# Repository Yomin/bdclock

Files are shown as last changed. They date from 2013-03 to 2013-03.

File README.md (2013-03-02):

# Bulbdial Clock Board

Board for the bulbdial clock developed at
[Evil Mad Scientist Laboratories](http://www.evilmadscientist.com/2009/a-bulbdial-clock/).
Due to current availability of only attiny45's the multiplexing is partly outsourced with
one 7bit binary counter and two 8bit addressable latches.

For synchronization the board is equipped with a socket for a pollin DCF77 module (810 054).

## License

MIT

## Parts

count|name|info
---|---|---|---
1x|attiny 25/45/85|
1x|HEF4024B|7 bit binary counter
1x|HCF4724B|8 bit addressable latch
2x|BC547B|
1x|red diffuse led|
1x|4pin socket|
1x|10pin isp socket|
1x|powerjack|
1x|2pin clamp|power
1x|3pin clamp|led gnd
1x|12pin clamp|led vcc
2x|1N4004|
1x|300nF|
1x|100nF|
1x|1uF pol|
1x|7805|
6x|10k|
1x|1k|
4x|250|
1x|pollin dcf77 module|
36x|white point leds|for the actual clock

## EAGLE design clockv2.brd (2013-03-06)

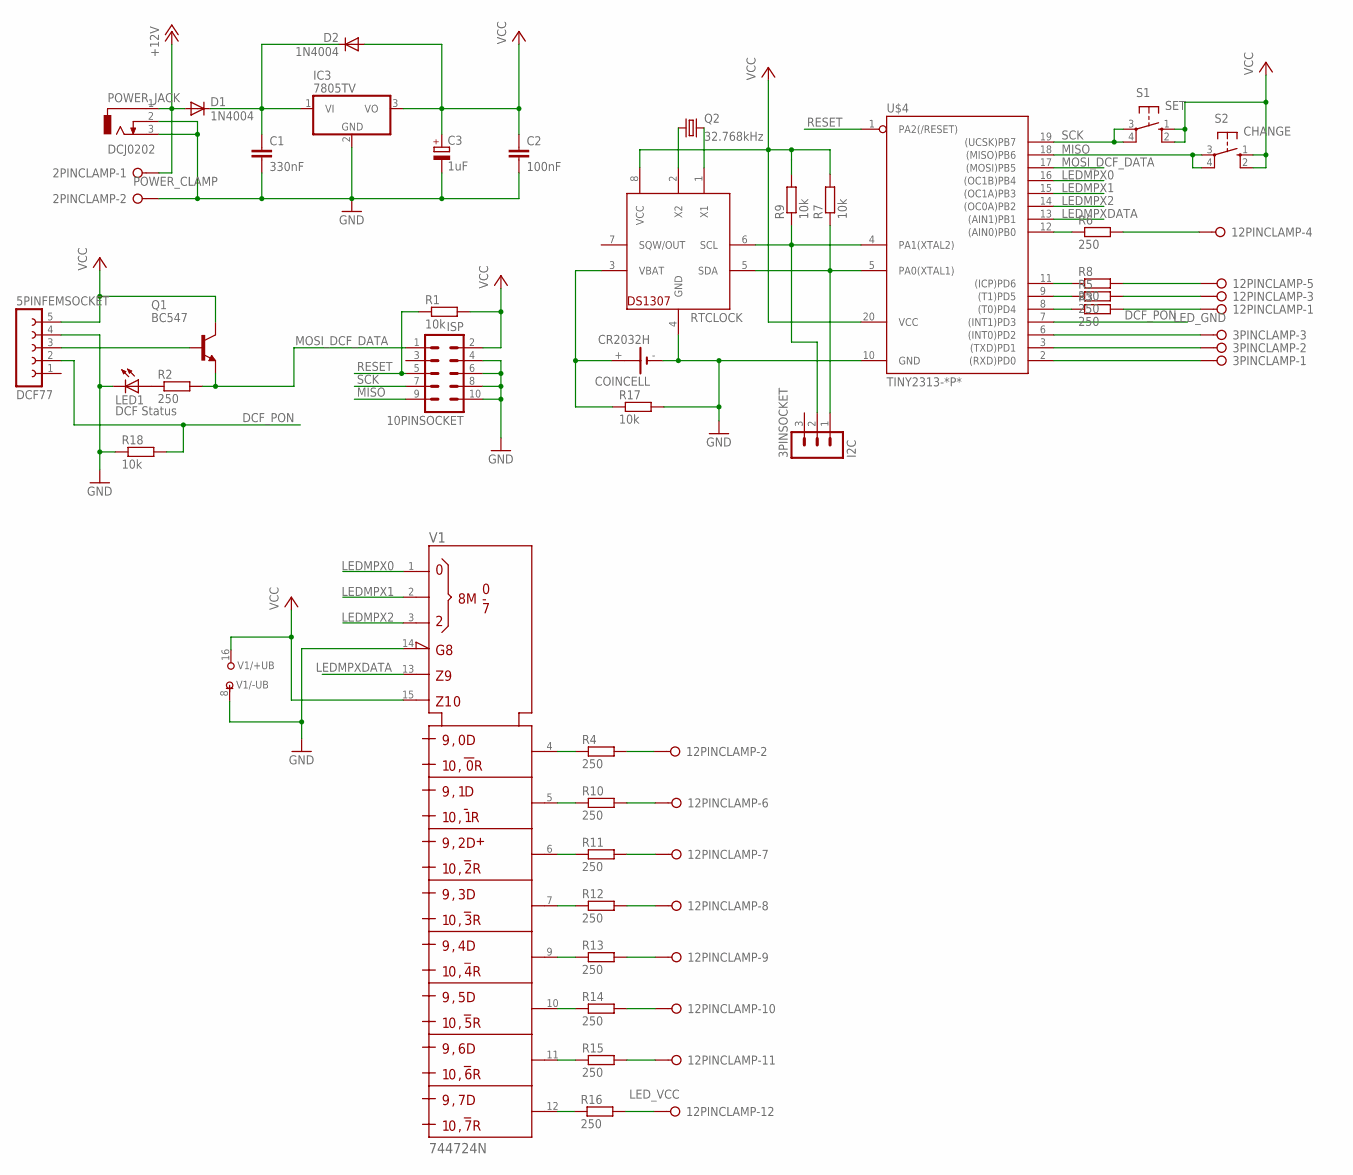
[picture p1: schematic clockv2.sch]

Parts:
2PINCLAMP: POWER_CLAMP; W237-132
3PINCLAMP: LED_GND; W237-133
3PINSOCKET: I2C; MA03-1
5PINFEMSOCKET: DCF77; FE05-1
10PINSOCKET: ISP; ML10
12PINCLAMP: LED_VCC; W237-12P
C1: 330nF; C050-025X075
C2: 100nF; C050-025X075
C3: 1uF; E2-4
COINCELL: CR2032H
D1, D2: 1N4004; DO41-10
IC3: 7805TV; TO220V
LED1: DCF Status; LED5MM
POWER_JACK: DCJ0202
Q1: BC547; TO92
Q2: 32.768kHz; TC38H
R1, R7, R9, R17, R18: 10k; 0204/5
R2, R3, R4, R5, R6, R8, R10, R11, R12, R13, R14, R15, R16: 250; 0204/5
RTCLOCK: DS1307; DIL08
S1: SET; B3F-10XX
S2: CHANGE; B3F-10XX
U$4: TINY2313-*P*; DIL20
V1: 744724N; DIL16

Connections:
+12V: 2PINCLAMP.1, D1.A, POWER_JACK.1
DCF_PON: 5PINFEMSOCKET.2, R18.2, U$4.7 ((INT1)PD3)
GND: 2PINCLAMP.2, 5PINFEMSOCKET.4, 10PINSOCKET.4, 10PINSOCKET.6, 10PINSOCKET.8, 10PINSOCKET.10, C1.2, C2.2, C3.-, COINCELL.-, IC3.2 (GND), LED1.K (C), POWER_JACK.2, POWER_JACK.3, R17.2, R18.1, RTCLOCK.4 (GND), U$4.10 (GND), V1.8 (-UB), V1.14 (!G)
LEDMPX0: U$4.16 ((OC1B)PB4), V1.1 (S0)
LEDMPX1: U$4.15 ((OC1A)PB3), V1.2 (S1)
LEDMPX2: U$4.14 ((OC0A)PB2), V1.3 (S2)
LEDMPXDATA: U$4.13 ((AIN1)PB1), V1.13 (D)
MISO: 10PINSOCKET.9, S2.3, S2.4 (P1), U$4.18 ((MISO)PB6)
MOSI_DCF_DATA: 10PINSOCKET.1, Q1.1 (E), R2.2, U$4.17 ((MOSI)PB5)
unnamed: 12PINCLAMP.4, R6.2
unnamed: 12PINCLAMP.2, R4.2
unnamed: 12PINCLAMP.3, R5.2
unnamed: 5PINFEMSOCKET.3, Q1.2 (B)
unnamed: 12PINCLAMP.1, R3.2
unnamed: 12PINCLAMP.5, R8.2
unnamed: 12PINCLAMP.6, R10.2
unnamed: R5.1, U$4.9 ((T1)PD5)
unnamed: R10.1, V1.5 (Q1)
unnamed: 12PINCLAMP.9, R13.2
unnamed: 12PINCLAMP.10, R14.2
unnamed: 12PINCLAMP.11, R15.2
unnamed: 12PINCLAMP.12, R16.2
unnamed: R3.1, U$4.8 ((T0)PD4)
unnamed: R4.1, V1.4 (Q0)
unnamed: LED1.A, R2.1
unnamed: C1.1, D1.C, D2.C, IC3.1 (VI)
unnamed: R6.1, U$4.12 ((AIN0)PB0)
unnamed: R8.1, U$4.11 ((ICP)PD6)
unnamed: 12PINCLAMP.8, R12.2
unnamed: 12PINCLAMP.7, R11.2
unnamed: R11.1, V1.6 (Q2)
unnamed: R12.1, V1.7 (Q3)
unnamed: R16.1, V1.12 (Q7)
unnamed: R13.1, V1.9 (Q4)
unnamed: R14.1, V1.10 (Q5)
unnamed: R15.1, V1.11 (Q6)
unnamed: 3PINCLAMP.3, U$4.6 ((INT0)PD2)
unnamed: 3PINCLAMP.2, U$4.3 ((TXD)PD1)
unnamed: 3PINCLAMP.1, U$4.2 ((RXD)PD0)
unnamed: 3PINSOCKET.2, R9.1, RTCLOCK.6 (SCL), U$4.4 (PA1(XTAL2))
unnamed: 3PINSOCKET.1, R7.1, RTCLOCK.5 (SDA), U$4.5 (PA0(XTAL1))
unnamed: COINCELL.+, R17.1, RTCLOCK.3 (VBAT)
unnamed: Q2.1, RTCLOCK.2 (X2)
unnamed: Q2.2, RTCLOCK.1 (X1)
RESET: 10PINSOCKET.5, R1.1, U$4.1 (PA2(/RESET))
SCK: 10PINSOCKET.7, S1.3, S1.4 (P1), U$4.19 ((UCSK)PB7)
VCC: 5PINFEMSOCKET.5, 10PINSOCKET.2, C2.1, C3.+, D2.A, IC3.3 (VO), Q1.3 (C), R1.2, R7.2, R9.2, RTCLOCK.8 (VCC), S1.1 (S), S1.2 (S1), S2.1 (S), S2.2 (S1), U$4.20 (VCC), V1.15 (CLR), V1.16 (+UB)

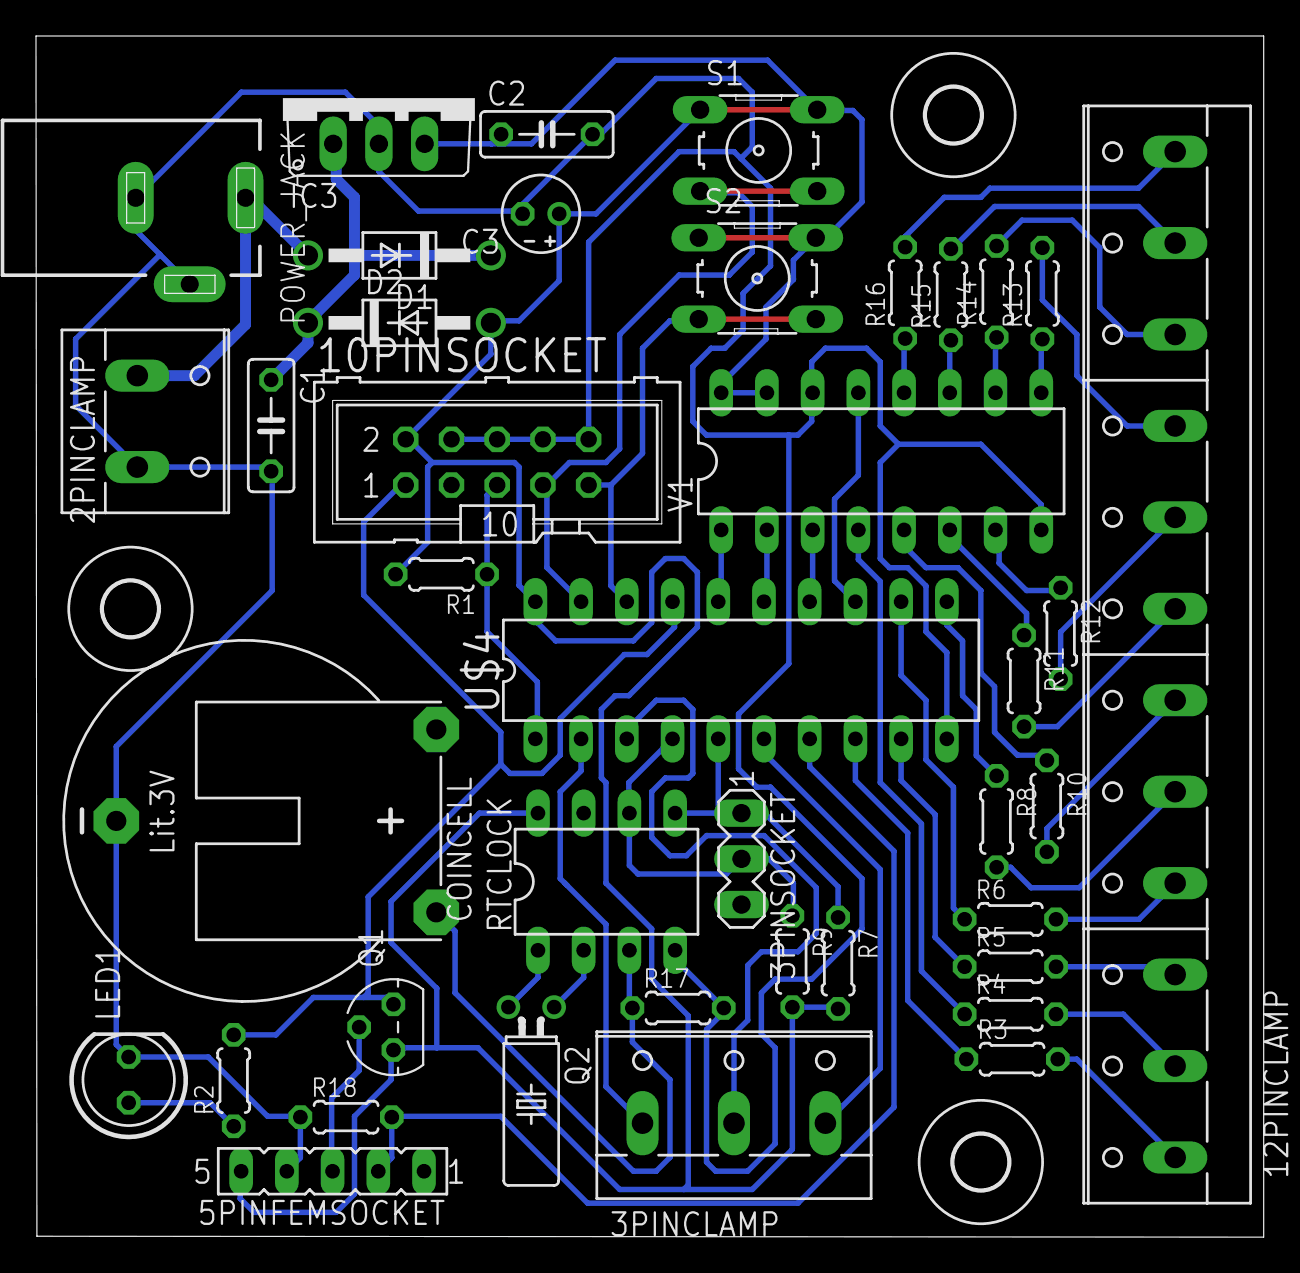
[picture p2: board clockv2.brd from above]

Board: 2 copper layers, 68.2 x 66.7 mm, 43 parts (0 on the bottom side), 47 nets.

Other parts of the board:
U$1, U$2, U$3: 3,0

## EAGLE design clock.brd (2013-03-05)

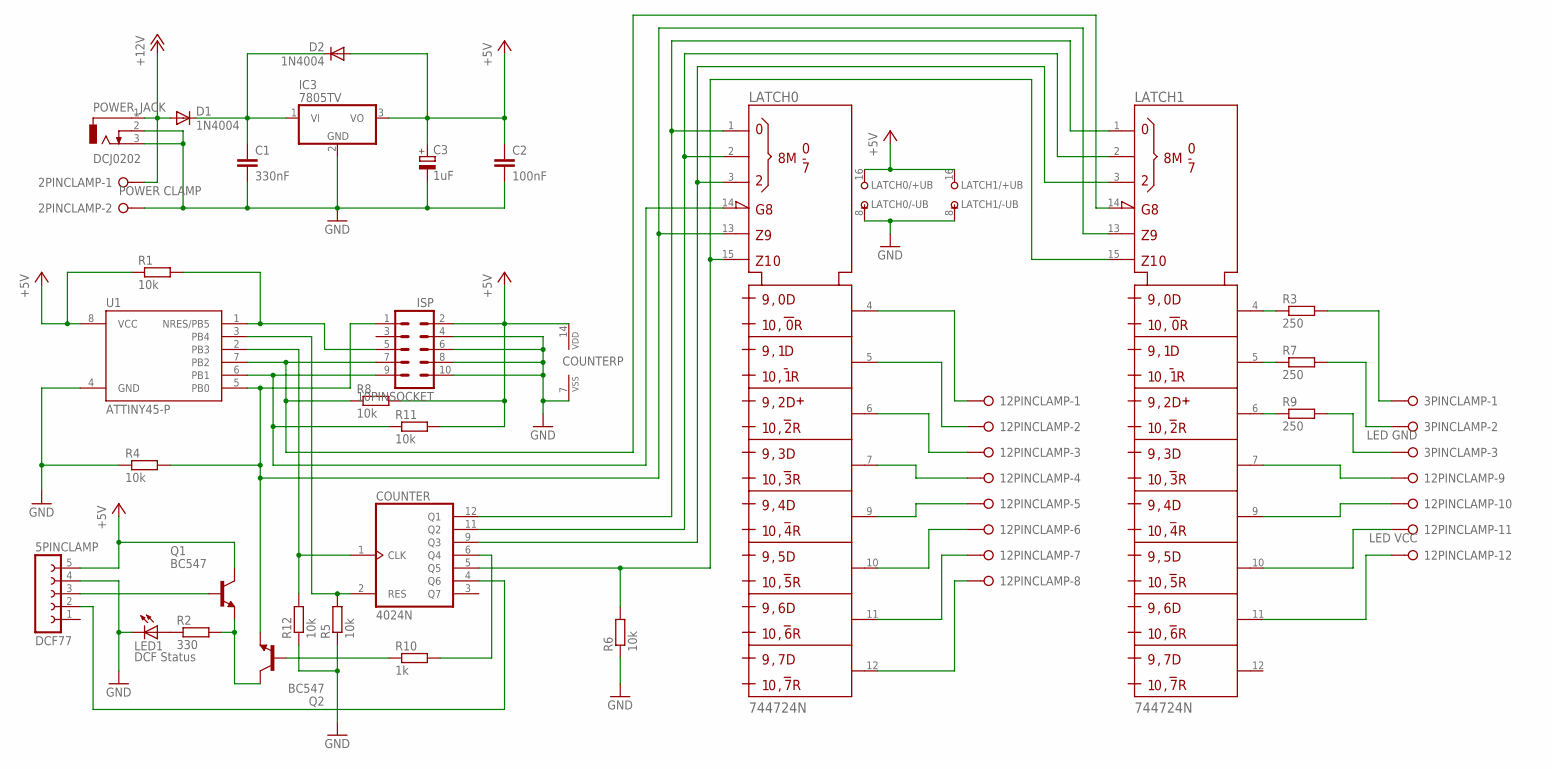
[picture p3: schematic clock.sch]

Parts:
2PINCLAMP: POWER CLAMP; W237-132
3PINCLAMP: LED GND; W237-3E
5PINCLAMP: DCF77; FE05-1
10PINSOCKET: ISP; ML10
12PINCLAMP: LED VCC; W237-12P
C1: 330nF; C050-025X075
C2: 100nF; C050-025X075
C3: 1uF; E2-4
COUNTER: 4024N; DIL14
D1, D2: 1N4004; DO41-10
IC3: 7805TV; TO220V
LATCH0, LATCH1: 744724N; DIL16
LED1: DCF Status; LED5MM
POWER_JACK: DCJ0202
Q1, Q2: BC547; TO92
R1, R4, R5, R6, R8, R11, R12: 10k; 0204/5
R2: 330; 0204/5
R3, R7, R9: 250; 0204/5
R10: 1k; 0204/5
U1: ATTINY45-P; PDIP08_300MIL

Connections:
+5V: 5PINCLAMP.5, 10PINSOCKET.2, C2.1, C3.+, COUNTER.14 (VDD), D2.A, IC3.3 (VO), LATCH0.16 (+UB), LATCH1.16 (+UB), Q1.3 (C), R1.1, R8.2, R11.2, U1.8 (VCC)
+12V: 2PINCLAMP.1, D1.A, POWER_JACK.1
CLOCK: COUNTER.1 (CLK), R12.2, U1.2 (PB3)
DATA: 10PINSOCKET.1, LATCH0.13 (D), LATCH1.13 (D), Q2.1 (E), R4.2, U1.5 (PB0)
DCF_DATA: 5PINCLAMP.3, Q1.2 (B)
DCF_PON: 5PINCLAMP.2, COUNTER.4 (Q6)
GND: 2PINCLAMP.2, 5PINCLAMP.4, 10PINSOCKET.4, 10PINSOCKET.6, 10PINSOCKET.8, 10PINSOCKET.10, C1.2, C2.2, C3.-, COUNTER.7 (VSS), IC3.2 (GND), LATCH0.8 (-UB), LATCH1.8 (-UB), LED1.K (C), POWER_JACK.2, POWER_JACK.3, R4.1, R5.1, R6.1, R12.1, U1.4 (GND)
LATCH0: 10PINSOCKET.7, LATCH1.14 (!G), R8.1, U1.7 (PB2)
LATCH1: 10PINSOCKET.9, LATCH0.14 (!G), R11.1, U1.6 (PB1)
unnamed: 12PINCLAMP.1, LATCH0.4 (Q0)
unnamed: 12PINCLAMP.6, LATCH0.10 (Q5)
unnamed: 12PINCLAMP.2, LATCH0.5 (Q1)
unnamed: 12PINCLAMP.8, LATCH0.12 (Q7)
unnamed: 12PINCLAMP.7, LATCH0.11 (Q6)
unnamed: 12PINCLAMP.5, LATCH0.9 (Q4)
unnamed: 12PINCLAMP.4, LATCH0.7 (Q3)
unnamed: 12PINCLAMP.3, LATCH0.6 (Q2)
unnamed: 3PINCLAMP.2, R7.2
unnamed: 3PINCLAMP.3, R9.2
unnamed: 12PINCLAMP.9, LATCH1.7 (Q3)
unnamed: LATCH1.4 (Q0), R3.1
unnamed: 12PINCLAMP.11, LATCH1.10 (Q5)
unnamed: 12PINCLAMP.12, LATCH1.11 (Q6)
unnamed: LED1.A, R2.1
unnamed: C1.1, D1.C, D2.C, IC3.1 (VI)
unnamed: Q1.1 (E), Q2.3 (C), R2.2
unnamed: LATCH1.6 (Q2), R9.1
unnamed: COUNTER.6 (Q4), R10.2
unnamed: LATCH1.5 (Q1), R7.1
unnamed: COUNTER.5 (Q5), LATCH0.15 (CLR), LATCH1.15 (CLR), R6.2
unnamed: 10PINSOCKET.5, R1.2, U1.1 (NRES/PB5)
unnamed: COUNTER.12 (Q1), LATCH0.1 (S0), LATCH1.1 (S0)
unnamed: Q2.2 (B), R10.1
unnamed: 3PINCLAMP.1, R3.2
unnamed: COUNTER.9 (Q3), LATCH0.3 (S2), LATCH1.3 (S2)
unnamed: COUNTER.11 (Q2), LATCH0.2 (S1), LATCH1.2 (S1)
unnamed: 12PINCLAMP.10, LATCH1.9 (Q4)
RESET: COUNTER.2 (RES), R5.2, U1.3 (PB4)

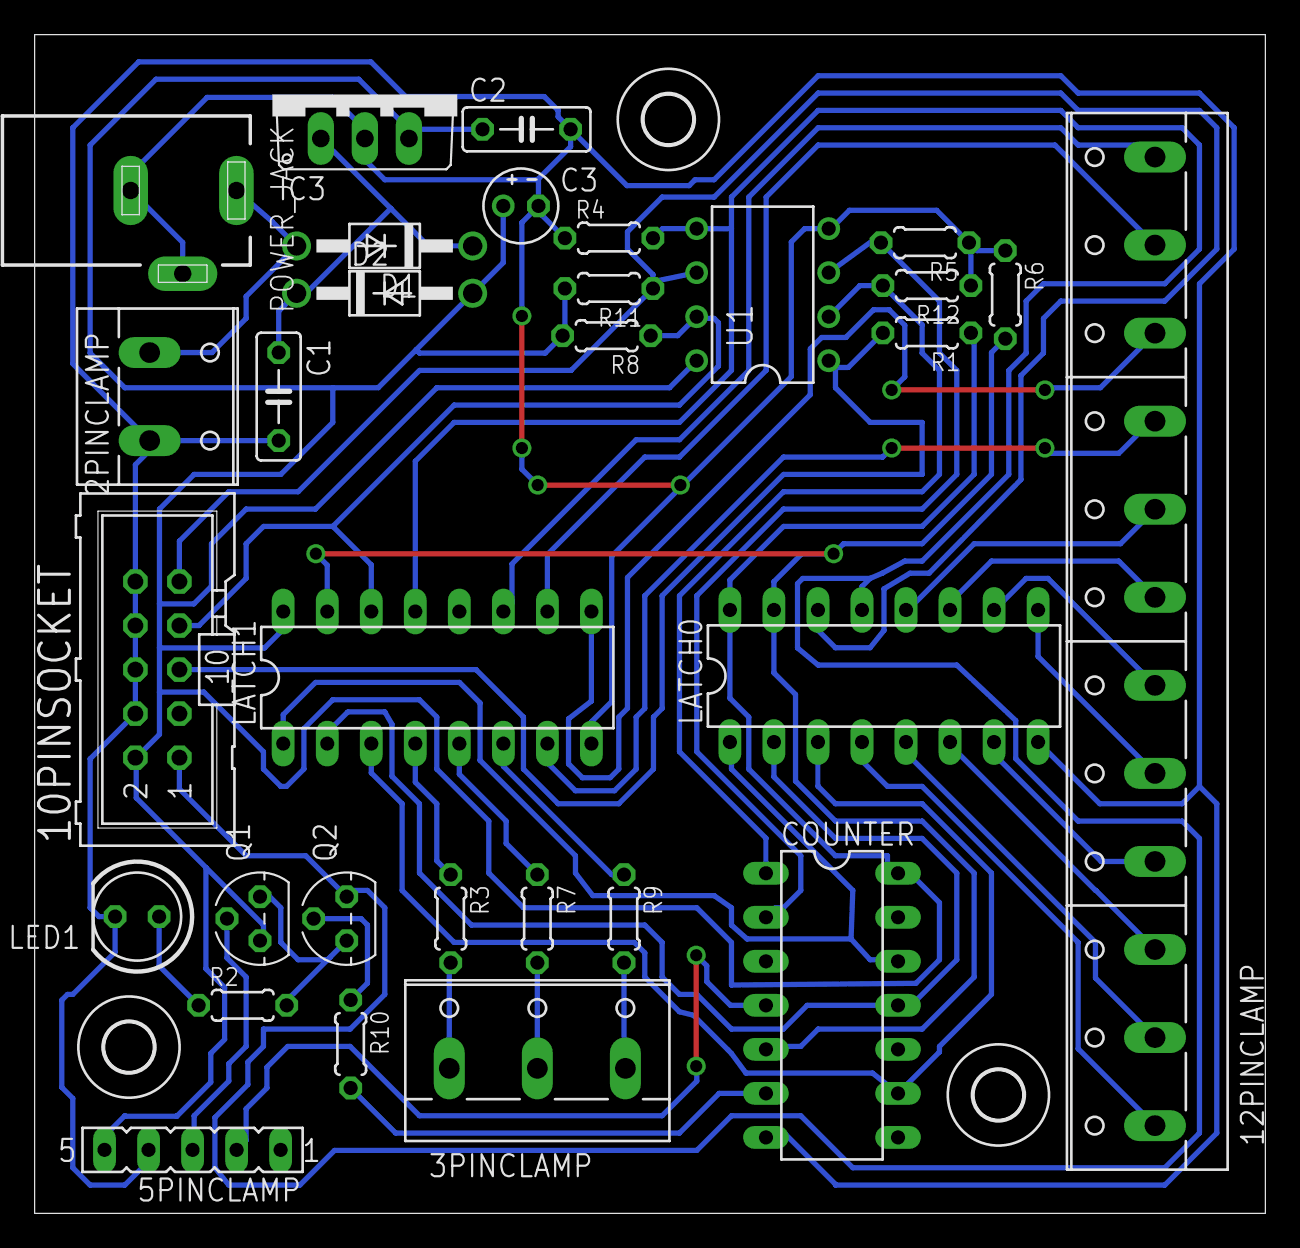
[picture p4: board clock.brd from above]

Board: 2 copper layers, 71.0 x 68.0 mm, 34 parts (0 on the bottom side), 38 nets.

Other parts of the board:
U$1, U$2, U$3: 2,8

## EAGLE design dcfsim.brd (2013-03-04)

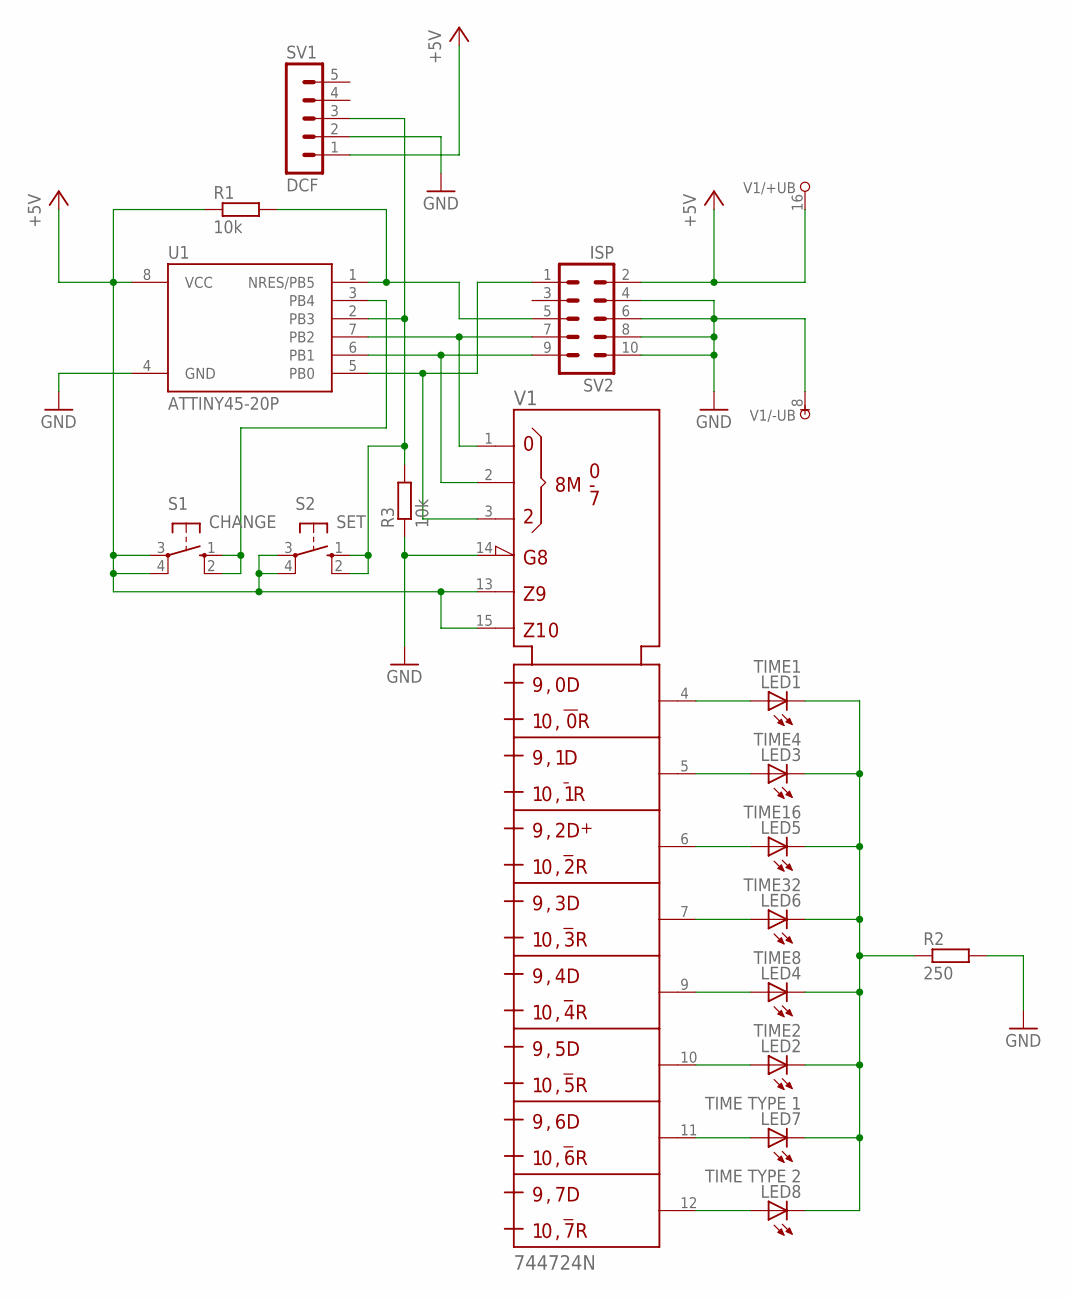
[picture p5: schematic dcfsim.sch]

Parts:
LED1: TIME1; LED5MM
LED2: TIME2; LED5MM
LED3: TIME4; LED5MM
LED4: TIME8; LED5MM
LED5: TIME16; LED5MM
LED6: TIME32; LED5MM
LED7: TIME TYPE 1; LED5MM
LED8: TIME TYPE 2; LED5MM
R1, R3: 10k; 0204/5
R2: 250; 0204/5
S1: CHANGE; B3F-10XX
S2: SET; B3F-10XX
SV1: DCF; MA05-1
SV2: ISP; ML10
U1: ATTINY45-20P; PDIP08_300MIL
V1: 744724N; DIL16

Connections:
+5V: R1.1, S1.3, S1.4 (P1), S2.3, S2.4 (P1), SV1.1, SV2.2, U1.8 (VCC), V1.13 (D), V1.15 (CLR), V1.16 (+UB)
GND: R2.2, R3.1, SV1.2, SV2.4, SV2.6, SV2.8, SV2.10, U1.4 (GND), V1.8 (-UB), V1.14 (!G)
unnamed: R1.2, SV2.5, U1.1 (NRES/PB5)
unnamed: SV2.7, U1.7 (PB2), V1.1 (S0)
unnamed: SV2.9, U1.6 (PB1), V1.2 (S1)
unnamed: SV2.1, U1.5 (PB0), V1.3 (S2)
unnamed: R3.2, S2.1 (S), S2.2 (S1), SV1.3, U1.2 (PB3)
unnamed: LED1.A, V1.4 (Q0)
unnamed: LED2.A, V1.10 (Q5)
unnamed: LED4.A, V1.9 (Q4)
unnamed: LED6.A, V1.7 (Q3)
unnamed: LED5.A, V1.6 (Q2)
unnamed: LED3.A, V1.5 (Q1)
unnamed: S1.1 (S), S1.2 (S1), U1.3 (PB4)
unnamed: LED7.A, V1.11 (Q6)
unnamed: LED8.A, V1.12 (Q7)
RROU: LED1.K (C), LED2.K (C), LED3.K (C), LED4.K (C), LED5.K (C), LED6.K (C), LED7.K (C), LED8.K (C), R2.1

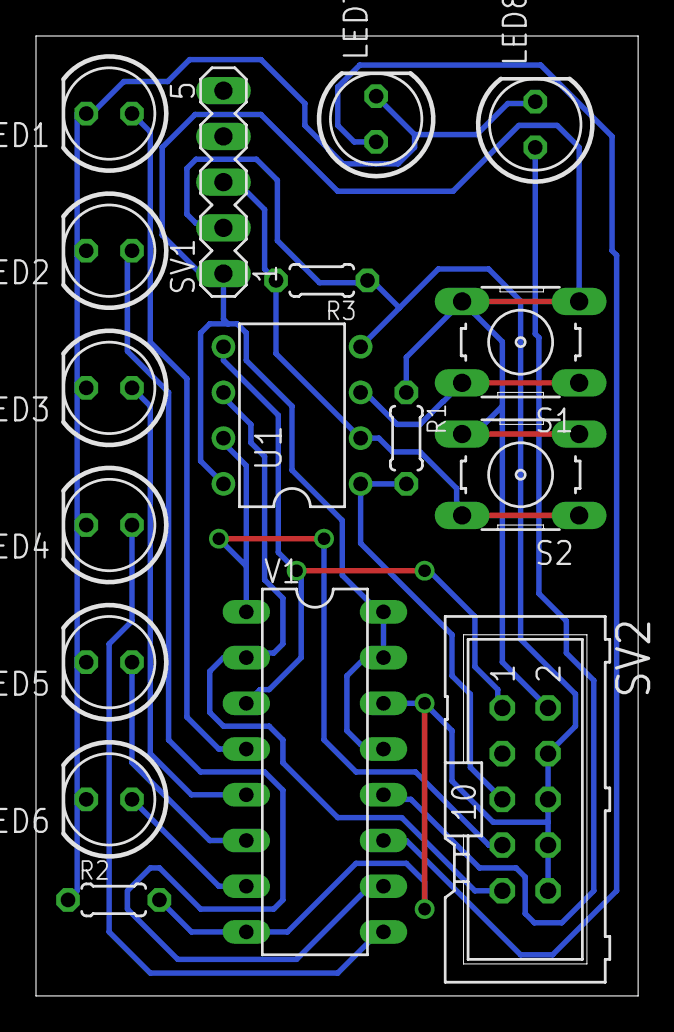
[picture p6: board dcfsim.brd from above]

Board: 2 copper layers, 33.5 x 53.3 mm, 17 parts (0 on the bottom side), 17 nets.

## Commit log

2013-03-01 initial commit, schematic and board done
    [clock.brd, clock.sch]
2013-03-02 change powerjack to horizontal, fix DRC errors, mirror logos and text, add gnd plane, set wire width to 12mil
    [clock.brd, clock.sch]
2013-03-03 fix ERC errors of schematic, add missing VCC/VSS pins of ICs, replace jumpers with vias
    [clock.brd, clock.sch]
2013-03-03 add DCF simulator board
    [clockset.brd, clockset.sch]
2013-03-04 rename clockset to dcfsim, move buttons upwards, move text to doc layer
    [dcfsim.brd, dcfsim.sch]
2013-03-04 rotate isp 180°, connect 4th gnd pin, move logo/text to doc layer
    [clock.brd, clock.sch, dcfsim.brd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]
2013-03-05 add restrict rect for oshw text
    [clock.brd]
2013-03-06 add clock v2
    [clockv2.brd, clockv2.sch]
